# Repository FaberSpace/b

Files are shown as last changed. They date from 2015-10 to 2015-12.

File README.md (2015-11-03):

# Ceas digital(afisaj cu tuburi)
----
###Functii
* Afisaj ora/data
* Afisaj temperatura
* Conectare usb

---
###Status
- [ ] Hardware
  - [x] Schema logica
  - [x] Layout
  - [x] Schema simulare
  - [ ] Implementare
- [ ] Software
  - [x] Adunare resurse
  - [x] Functii de baza
  - [ ] Software matur
  
  ---
###Descriere hardware

-  Afisajul consta in 4 tuburi rusesti de tip IV-9 numitron: 2 pentru ora si 2 ore pentru minute. Fiecare tub are un afisaj cu 7 segmente de tip filament. Acestea se alimenteaza la tensiuni joase si au nevoie de aproximativ 20 mA pentru a lumina. 
- MAX7219 – driver-ul care controleaza afisajele cu 7 segmente; are cate o iesire pentru fiecare digit in parte; comunica cu uC prin interfata SPI
- DS1307 – Real time clock (RTC) – ne da ora in format BCD ; datele si adresele sunt transmise prin protocolul I2C
- LM75 – senzor IC  digital de temperatura; comunica cu uC prin protocolul I2C; senzorul masoara temperatura materialului semiconductor din interior
- HC-SR505 – sensor PIR (passive infrared sensor); masoara cantitatea de lumina IR radiata de obiectele din jurul sau. 
- uC – ATMEGA328P – uC pe 8 biti cu 32 pini
- MICRO-USB – (tip B) 
- 3 butoane: pentru functie (ceas/temperatura), ora si minute
- In layout am folosit un conector de 8 pini la care vor fi legate ulterior segmentele afisajelor si un conector de 4 pini pentru digiti. Am adoptat aceasta abordare pentru a ocupa cat mai putin spatiu pe placa avand in vedere ca elementele de afisaj sunt legate in paralel. Electronica se va afla in interiorul unei carcase.

----

###Referinte:
- [Biblioteca LedControl](http://playground.arduino.cc/Main/LedControl)
- [Biblioteca RTC](https://github.com/adafruit/RTClib)
- [Biblioteca LM75](https://github.com/thefekete/LM75)
- TBA

----

###Evolutie
 > TBA

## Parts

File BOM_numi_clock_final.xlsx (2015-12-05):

Part | Value | Device | Package | Description | Link | Distribuitor | Pret
BAT2 | cr2032 | BATTERY20PTH | BATTCOM_20MM_PTH | Battery Holders
C1 | 100nF | C-EU0805 | 805 | CAPACITOR
C2 | 22pF | C-EU0805 | 805 | CAPACITOR
C3 | 22pF | C-EU0805 | 805 | CAPACITOR
C4 | 100nF | C-EU0805 | 805 | CAPACITOR
C5 | 100nF | C-EU0805 | 805 | CAPACITOR
C9 | 27pF | C-EU0805 | 805 | CAPACITOR
C10 | 27pF | C-EU0805 | 805 | CAPACITOR
D1 | 3.6V | DIODE-ZENER3.3V | SOD-323 | Zener Diode
D2 | 3.6V | DIODE-ZENER3.3V | SOD-323 | Zener Diode
D3 |  | LED | 805 | Light Emitting Diode
IC1 | ATMEGA328P | ATMEGA328P | TQFP32-08 | MICROCONTROLLER | (LINK) (http://www.adelectrocom.ro/product_info.php/products_id/123783) | Adelectrocom | 8.9
IC2 | LM75 | LM75_ICN | SO8_LM75 | Temperatursensor | (LINK) (http://www.adelectrocom.ro/product_info.php/products_id/46791) | Adelectrocom | 4.18
JP1 | micro-usb | USB_MICROB_PLUGCONN-11752 | USB-B-MICRO-SMD_V03 | USB Micro-B connectors
Q1 | 12MHz | CRYSTALCTS406 | CTS406 | CRYSTAL | (LINK) (http://www.adelectrocom.ro/product_info.php/cPath/536_28/products_id/4350) | Adelectrocom | 0.62
R1 | 10k | R-EU_0805 | 805 | RESISTOR | (LINK) (http://www.adelectrocom.ro/product_info.php/cPath/536_2_560/products_id/77904) | Adelectrocom | 0.05
R2 | 68 | R-EU_0805 | 805 | RESISTOR
R3 | 1.8k | R-EU_0805 | 805 | RESISTOR
R4 | 68 | R-EU_0805 | 805 | RESISTOR
R8 | 10k | R-EU_0805 | 805 | RESISTOR
R10 | 10k | R-EU_0805 | 805 | RESISTOR
R11 | 23k | R-EU_0805 | 805 | RESISTOR
S1 | SWITCH-MOMENTARY-2TACTILE-SWITCH-SMD-RIGHT-ANGLE | SWITCH-MOMENTARY-2TACTILE-SWITCH-SMD-RIGHT-ANGLE | TACTILE_SWITCH-SMD-RIGHT-ANGLE
S2 | SWITCH-MOMENTARY-2TACTILE-SWITCH-SMD-RIGHT-ANGLE | SWITCH-MOMENTARY-2TACTILE-SWITCH-SMD-RIGHT-ANGLE | TACTILE_SWITCH-SMD-RIGHT-ANGLE | Various NO switches- pushbuttons
S3 | SWITCH-MOMENTARY-2TACTILE-SWITCH-SMD-RIGHT-ANGLE | SWITCH-MOMENTARY-2TACTILE-SWITCH-SMD-RIGHT-ANGLE | TACTILE_SWITCH-SMD-RIGHT-ANGLE | Various NO switches- pushbuttons
SV2 | HC-SR505 | MA03-1 | MA03-1 | PIN HEADER
SV3 |  | MA08-1 | MA08-1 | PIN HEADER
SV8 | conn digits | MA04-1 | MA04-1 | PIN HEADER
U$1 | MAX7219CWG | MAX7219CWG | SO24L |  | (LINK) (http://www.adelectrocom.ro/product_info.php/products_id/72037) | Adelectrocom | 19.8
U$2 | DS1307SO8 | DS1307SO8 | SO08 | I2C real-time clock with battery backup. | (LINK) (http://www.adelectrocom.ro/product_info.php/products_id/38998) | Adelectrocom | 5.39
Y1 | 32.768kHz | CRYSTALTC26H | TC26H | Various standard crystals. Proven footprints.

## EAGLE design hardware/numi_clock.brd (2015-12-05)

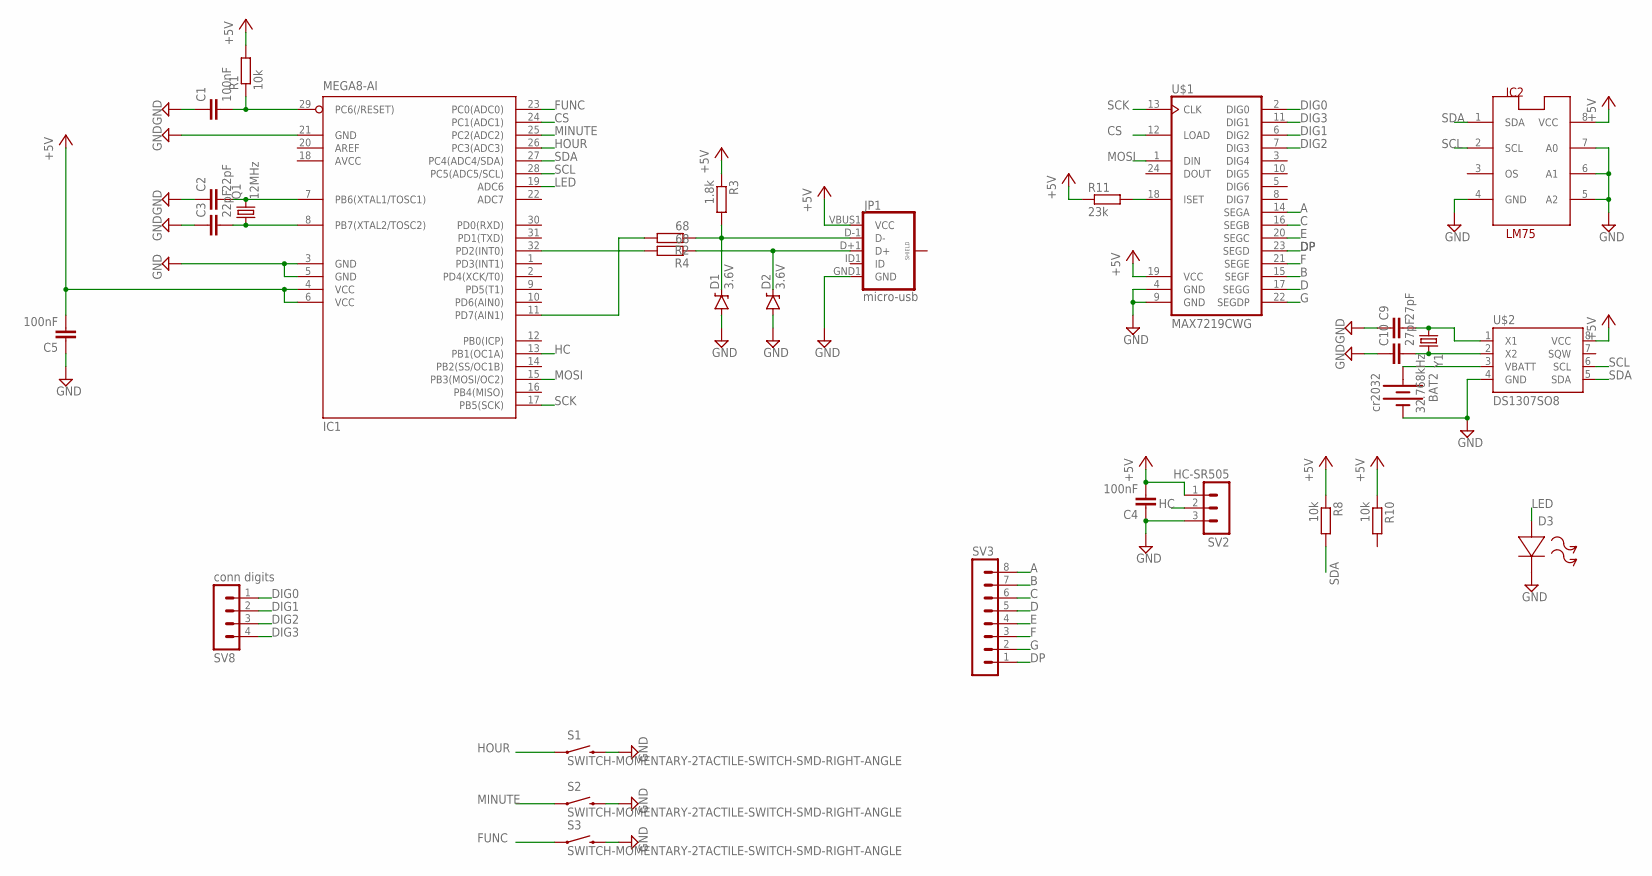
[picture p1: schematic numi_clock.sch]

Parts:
BAT2: cr2032; BATTCOM_20MM_PTH
C1, C4, C5: 100nF; C0805
C2, C3: 22pF; C0805
C9, C10: 27pF; C0805
D1, D2: 3.6V; SOD-323
D3: LED; R0805
IC1: MEGA8-AI; TQFP32-08
IC2: LM75; SO8_LM75
JP1: micro-usb; USB-B-MICRO-SMD_V03
Q1: 12MHz; CTS406
R1, R8, R10: 10k; R0805
R2, R4: 68; R0805
R3: 1.8k; R0805
R11: 23k; R0805
S1, S2, S3: SWITCH-MOMENTARY-2TACTILE-SWITCH-SMD-RIGHT-ANGLE; TACTILE_SWITCH-SMD-RIGHT-ANGLE
SV2: HC-SR505; MA03-1
SV3: MA08-1
SV8: conn digits; MA04-1
U$1: MAX7219CWG; SO24L
U$2: DS1307SO8; SO08
Y1: 32.768kHz; TC26H

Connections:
+5V: C4.2, C5.2, IC1.4 (VCC), IC1.6 (VCC), IC2.8 (VCC), JP1.VBUS1 (VCC), R1.2, R3.1, R8.1, R10.1, R11.1, SV2.1, U$1.19 (VCC), U$2.8 (VCC)
A: SV3.8, U$1.14 (SEGA)
AVCC: IC1.18 (AVCC)
B: SV3.7, U$1.15 (SEGF)
C: SV3.6, U$1.16 (SEGB)
CS: IC1.24 (PC1(ADC1)), U$1.12 (LOAD)
D: SV3.5, U$1.17 (SEGG)
DIG0: SV8.1, U$1.2 (DIG0)
DIG1: SV8.2, U$1.6 (DIG2)
DIG2: SV8.3, U$1.7 (DIG3)
DIG3: SV8.4, U$1.11 (DIG1)
DP: SV3.1, U$1.23 (SEGD)
E: SV3.4, U$1.20 (SEGC)
F: SV3.3, U$1.21 (SEGE)
FUNC: IC1.23 (PC0(ADC0)), S3.1
G: SV3.2, U$1.22 (SEGDP)
GND: BAT2.2 (-), C1.1, C2.1, C3.1, C4.1, C5.1, C9.1, C10.1, D1.A, D2.A, D3.2 (-), IC1.3 (GND), IC1.5 (GND), IC1.21 (GND), IC2.4 (GND), IC2.5 (A2), IC2.6 (A1), IC2.7 (A0), JP1.GND1 (GND), S1.2, S2.2, S3.2, SV2.3, U$1.4 (GND), U$1.9 (GND), U$2.4 (GND)
HC: IC1.13 (PB1(OC1A)), SV2.2
HOUR: IC1.26 (PC3(ADC3)), S1.1
LED: D3.1 (+), IC1.19 (ADC6)
MINUTE: IC1.25 (PC2(ADC2)), S2.1
MOSI: IC1.15 (PB3(MOSI/OC2)), U$1.1 (DIN)
unnamed: C2.2, IC1.7 (PB6(XTAL1/TOSC1)), Q1.3 (2)
unnamed: C3.2, IC1.8 (PB7(XTAL2/TOSC2)), Q1.1
unnamed: R11.2, U$1.18 (ISET)
unnamed: C9.2, U$2.1 (X1), Y1.1
unnamed: C10.2, U$2.2 (X2), Y1.2
unnamed: BAT2.1 (+), U$2.3 (VBATT)
unnamed: D2.C, JP1.D+1 (D+), R4.1
unnamed: D1.C, JP1.D-1 (D-), R2.1, R3.2
unnamed: IC1.32 (PD2(INT0)), R4.2
unnamed: IC1.11 (PD7(AIN1)), R2.2
RESET: C1.2, IC1.29 (PC6(/RESET)), R1.1
SCK: IC1.17 (PB5(SCK)), U$1.13 (CLK)
SCL: IC1.28 (PC5(ADC5/SCL)), IC2.2 (SCL), U$2.6 (SCL)
SDA: IC1.27 (PC4(ADC4/SDA)), IC2.1 (SDA), R8.2, U$2.5 (SDA)

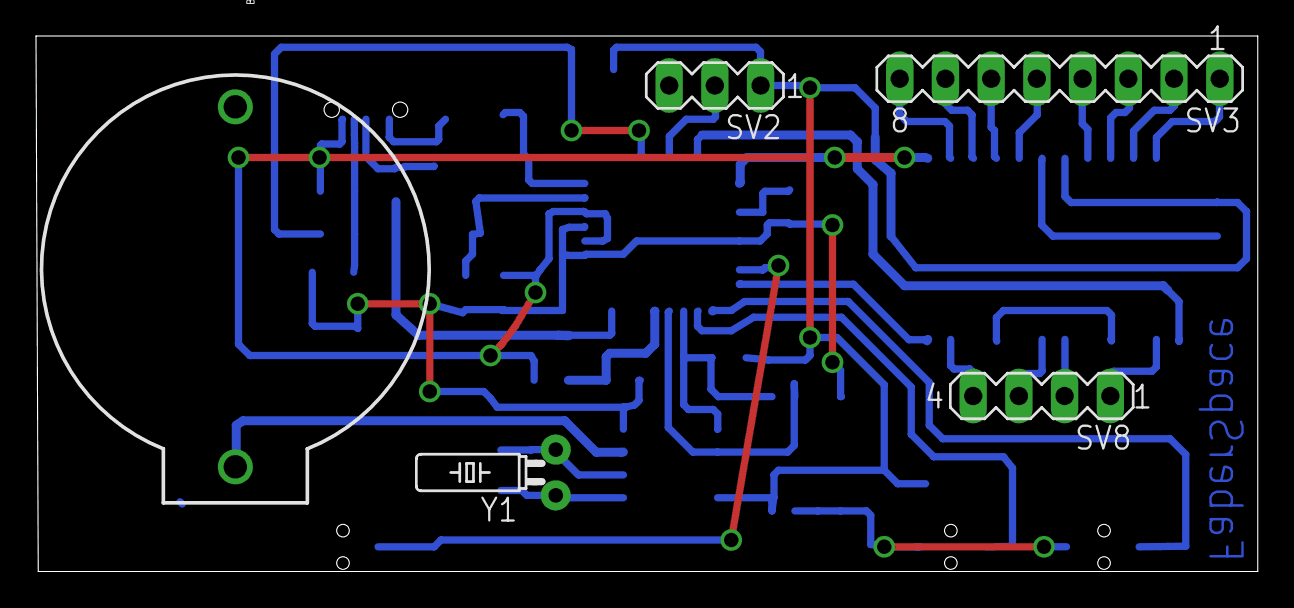
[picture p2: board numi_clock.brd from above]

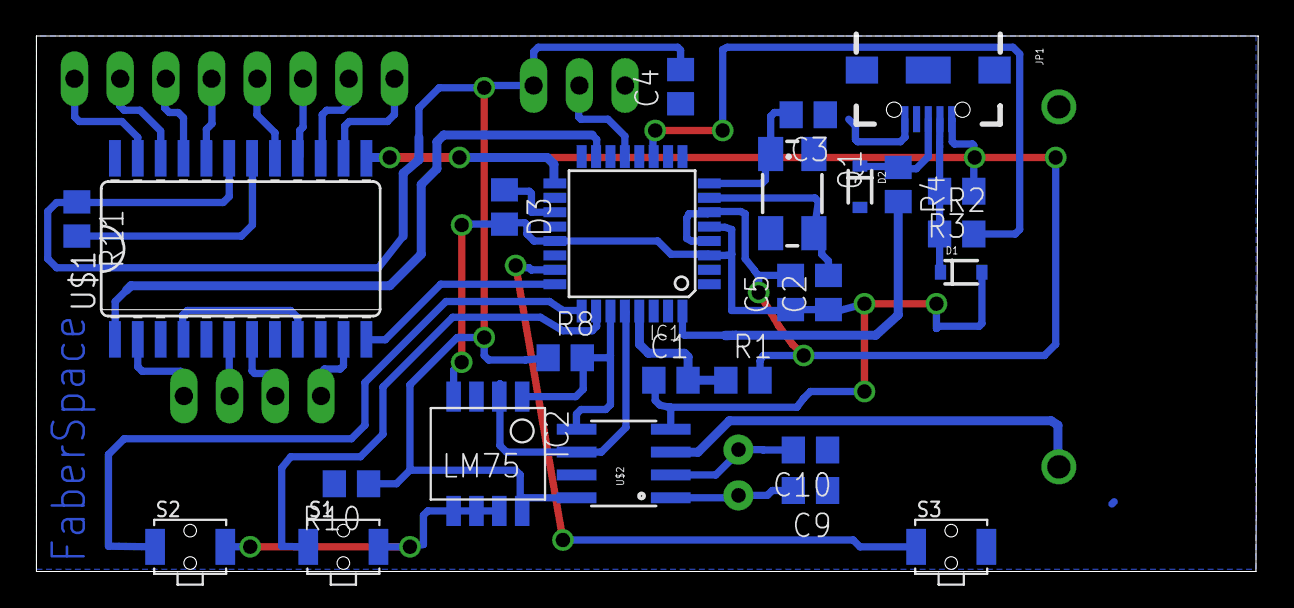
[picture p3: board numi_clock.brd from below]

Board: 2 copper layers, 67.9 x 29.8 mm, 31 parts (26 on the bottom side), 35 nets.

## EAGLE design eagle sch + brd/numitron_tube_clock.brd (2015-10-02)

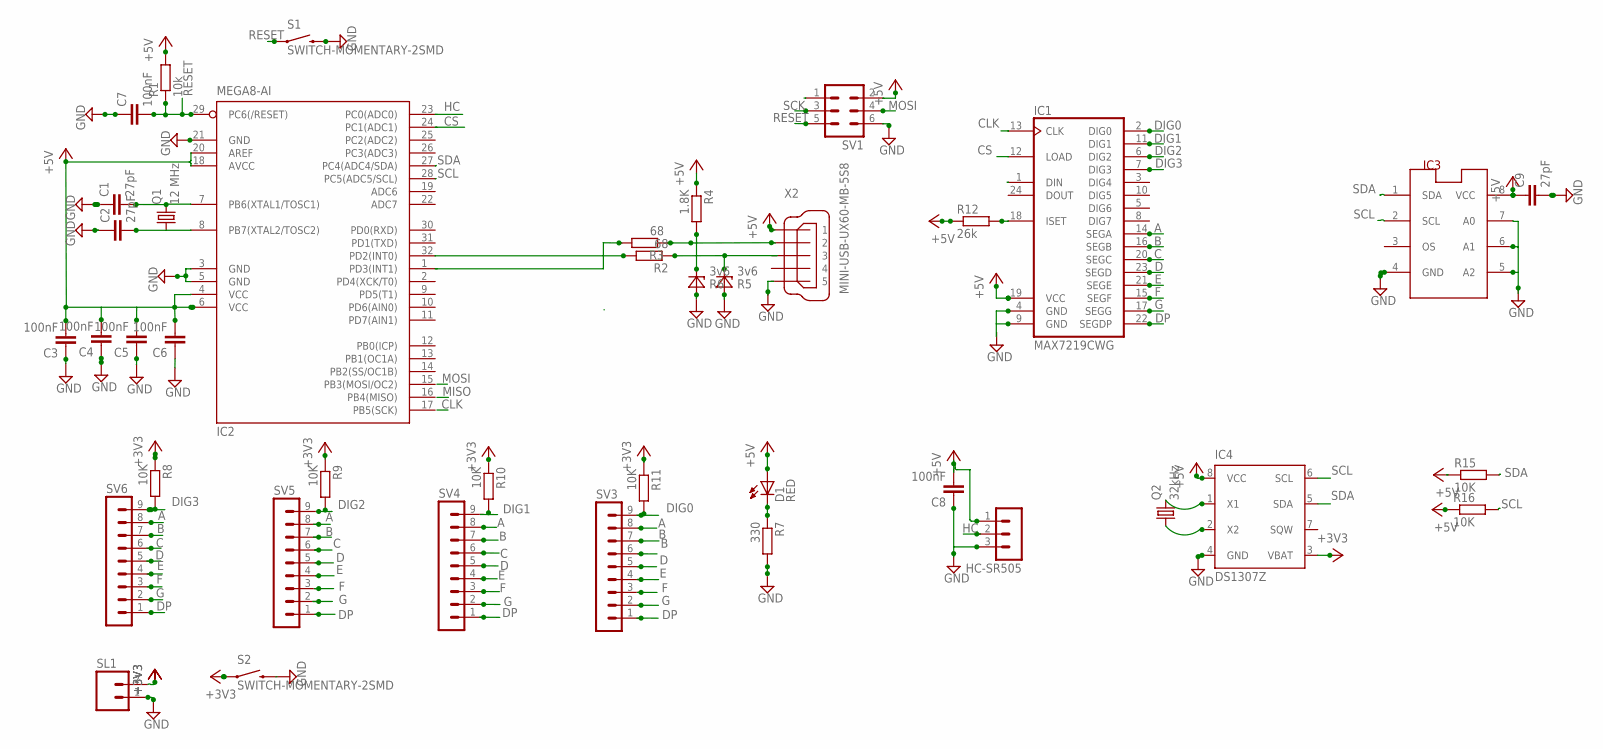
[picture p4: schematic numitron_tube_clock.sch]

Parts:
C1, C2, C9: 27pF; C0805
C3, C4, C5, C6, C7, C8: 100nF; C0805
D1: RED; HLMP6
HC-SR505: MA03-1
IC1: MAX7219CWG; SO24L
IC2: MEGA8-AI; TQFP32-08
IC3: LM75_ICN; SO8_LM75
IC4: DS1307Z; SOIC8
Q1: 12 MHz; HC49U-V
Q2: 32kHz; HC49U-V
R1: 10k; M0805
R2, R3: 68; M0805
R4: 1.8K; M0805
R5, R6: 3v6; Z-DIODE
R7: 330; M0805
R8, R9, R10, R11, R15, R16: 10K; M0805
R12: 26k; M0805
S1, S2: SWITCH-MOMENTARY-2SMD; TACTILE-SWITCH-SMD
SL1: MA02; 02PA
SV1: MA03-2
SV3, SV4, SV5, SV6: MA09-1
X2: MINI-USB-UX60-MB-5S8; UX60-MB-5S8

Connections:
+3V3: IC4.3 (VBAT), R11.1, S2.1
+5V: C3.2, C4.2, C5.2, C6.2, C8.2, D1.A, IC1.19 (VCC), IC2.6 (VCC), IC2.18 (AVCC), IC2.20 (AREF), IC4.8 (VCC), R4.1, R12.1, R15.1, R16.1, X2.1
A: IC1.14 (SEGA), SV3.8, SV4.8, SV5.8, SV6.8
B: IC1.16 (SEGB), SV3.7, SV4.7, SV5.7, SV6.7
C: IC1.20 (SEGC), SV4.6, SV5.6, SV6.6
CLK: IC1.13 (CLK)
CS: IC1.12 (LOAD), IC2.24 (PC1(ADC1))
D: IC1.23 (SEGD), SV3.5, SV4.5, SV5.5, SV6.5
DIG0: IC1.2 (DIG0), SV3.9
DIG1: IC1.11 (DIG1)
DIG2: IC1.6 (DIG2), SV5.9
DIG3: IC1.7 (DIG3), R8.2, SV6.9
DP: IC1.22 (SEGDP), SV3.1, SV4.1, SV5.1, SV6.1
E: IC1.21 (SEGE), SV3.4, SV4.4, SV5.4, SV6.4
F: IC1.15 (SEGF), SV3.3, SV4.3, SV5.3, SV6.3
G: IC1.17 (SEGG), SV3.2, SV4.2, SV5.2, SV6.2
GND: C1.1, C3.1, C4.1, C5.1, C6.1, C7.1, C8.1, C9.2, HC-SR505.3, IC2.3 (GND), IC2.5 (GND), IC2.21 (GND), IC3.6 (A1), IC3.7 (A0), IC4.4 (GND), R5.A, R7.2, S1.3 (2), S2.3 (2), SL1.1, SV1.6
HC: HC-SR505.2, IC2.23 (PC0(ADC0))
MISO: SV1.1
MOSI: IC1.1 (DIN), SV1.4
unnamed: C1.2, Q1.2
unnamed: C2.2, Q1.1
unnamed: R2.1, X2.3
unnamed: R3.1, R4.2, X2.2
unnamed: IC2.32 (PD2(INT0)), R2.2
unnamed: C9.1, IC3.8 (VCC)
unnamed: IC1.18 (ISET), R12.2
unnamed: D1.K, R7.1
unnamed: IC4.2 (X2), Q2.1
unnamed: IC4.1 (X1), Q2.2
unnamed: IC1.4 (GND), IC1.9 (GND)
RESET: C7.2, IC2.29 (PC6(/RESET)), SV1.5
SCK: SV1.3
SCL: IC2.28 (PC5(ADC5/SCL)), IC3.2 (SCL), IC4.6 (SCL), R16.2
SDA: IC2.27 (PC4(ADC4/SDA)), IC3.1 (SDA), IC4.5 (SDA), R15.2

Board: 2 copper layers, 40 parts (0 on the bottom side), 31 nets, no tracks yet.

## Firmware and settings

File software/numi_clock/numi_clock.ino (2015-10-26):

/*
Author: Vadim Radu
Date: 26/10/2015

Credits:

*/
// Date and time functions using a DS1307 RTC connected via I2C and Wire lib
//Display functions using MAX7219 
 
#include <Wire.h>
#include "RTClib.h"
#include "LedControl.h"

//constants
#define CLK
#define DATA
#define LATCH
#define DEV_NR

//component declarations 
RTC_DS1307 RTC;
LedControl lc=LedControl(CLK, DATA, LATCH, DEV_NR);

void setup() {
   Serial.begin(115200);
   Wire.begin();
   RTC.begin();
   lc.shutdown(0,false);
   lc.setIntensity(0,1);
   lc.clearDisplay(0);
   
 //debug purpose
  if (! RTC.isrunning()) {
    Serial.println("RTC is NOT running!");
    RTC.adjust(DateTime(__DATE__, __TIME__)); // sets the RTC to the date & time this sketch was compiled
  }
 
  
  
  
}

void printNumber(int v, ) {
    int ones;
    int tens;
    
    ones=v%10;
    v=v/10;
    tens=v%10;
    	
    //Now print the number digit by digit
    lc.setDigit(0,2,(byte)hundreds,false);
    lc.setDigit(0,1,(byte)tens,false);
    lc.setDigit(0,0,(byte)ones,false);
}

void loop() { 
   DateTime now = RTC.now();
 
 
 
 //debbuging purpose
    Serial.print(now.year(), DEC);      Serial.print('/');
    Serial.print(now.month(), DEC);     Serial.print('/');
    Serial.print(now.day(), DEC);       Serial.print(' ');
    Serial.print(now.hour(), DEC);      Serial.print(':');
    Serial.print(now.minute(), DEC);    Serial.print(':');
    Serial.print(now.second(), DEC);    Serial.println();
 
}

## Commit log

2015-10-01 added sch file for numi clock
    eagle sch file
    [numitron_tube_clock.sch]
2015-10-02 create gitignore
    added proper gitignore for current project
2015-10-02 made folders
    made folders
    [numitron_tube_clock.sch]
2015-10-02 added BOM
    added BOM
    [BOM.xlsx]
2015-10-02 added power button and generated board
    added power button and generated board
    [BOM.xlsx, numitron_tube_clock.brd, numitron_tube_clock.sch]
2015-10-03 Fixes #1
    Fixes #1
    [numi_clock-BOM.xlsx, numi_clock.brd, numi_clock.sch]
2015-10-03 added buttons for hour, minute, function
    added buttons for hour, minute, function
    [numi_clock.brd, numi_clock.sch]
2015-10-03 minor changes
    minor changes
    [numi_clock.brd, numi_clock.sch]
2015-10-07 layout adjustments
    layout adjustments
    [numi_clock.brd, numi_clock.sch]
2015-10-18 later edit
    later edit
    [numi_clock.brd]
2015-10-18 routed all tracks
    routed all tracks
    [numi_clock.brd, numi_clock.sch]
2015-10-20 first software upload
    restructured directory tree, commit barebone max7219 example
    [numi_clock.brd, numi_clock.sch]
2015-11-05 rerouted some tracks
    rerouted some tracks
    [numi_clock.brd, numi_clock.sch]
2015-12-05 added final BOM
    added final BOM
    [BOM.xlsx, BOM_numi_clock_final.xlsx, numi_clock-BOM.xlsx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]

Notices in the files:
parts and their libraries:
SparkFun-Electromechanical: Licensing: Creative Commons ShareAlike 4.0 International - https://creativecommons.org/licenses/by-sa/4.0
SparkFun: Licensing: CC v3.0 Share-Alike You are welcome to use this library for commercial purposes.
